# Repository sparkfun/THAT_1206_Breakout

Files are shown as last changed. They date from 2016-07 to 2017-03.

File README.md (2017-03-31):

SparkFun THAT 1206 Breakout
========================================

THAT-1206 Breakout

[*BOB-14002*](https://www.sparkfun.com/products/14002)

The SparkFun THAT 1206 InGenius Breakout Board offers an easy solution to adding a balanced audio input to your circuits. The THAT InGenius technology has been designed for high-grade analog line receiving and offers a low distortion and high common mode rejection in real-world audio applications. Each breakout board combines the THAT 1206 IC, its supporting components, and a ¼" TRS (Tip Ring Sleeve) socket. With these powers combined, you will find it very easy to use the input drivers on breadboards and in projects!

The THAT 1206 InGenius Breakout and its sibling, the THAT 1646 OutSmarts Breakout, perform mirror-image signal conversion. While the OutSmarts is an unbalanced-to-balanced output driver, this InGenius is a balanced-to-unbalanced input receiver. We have made sure to break out each pin you need to utilize the InGenius board, including the unbalanced output (OUT), the positive and negative power supply rails (V+, V-) and, of course, ground (GND). Additionally, adjacent to each leg of the socket are test points for the signal (T, R, S) and normal (TN, RN, SN) contacts.

Repository Contents
-------------------

* **/Hardware** - Eagle design files (.brd, .sch)
* **/Production** - Production panel files (.brd)

Documentation
--------------
* **[Hookup Guide](https://learn.sparkfun.com/tutorials/that-ingenuis-and-outsmarts-breakout-hookup-guide)** - Basic hookup guide for the THAT 1206 and 1646 breakouts.
* **[SparkFun Fritzing repo](https://github.com/sparkfun/Fritzing_Parts)** - Fritzing diagrams for SparkFun products.
* **[SparkFun 3D Model repo](https://github.com/sparkfun/3D_Models)** - 3D models of SparkFun products.

Product Versions
----------------
* [BOB-14002](https://www.sparkfun.com/products/14002) - THAT 1206 InGenius breakout board.
* [BOB-14003](https://www.sparkfun.com/products/14003) - The companion THAT 1646 OutSmarts breakout board.

Version History
---------------
* [V1.0 Tag](https://github.com/sparkfun/THAT_1206_Breakout/commit/8fa3e24b62fe93f8f912508c355df1751a37f655) - Files as of product launch.

License Information
-------------------

This product is _**open source**_!

Please review the LICENSE.md file for license information.

If you have any questions or concerns on licensing, please contact techsupport@sparkfun.com.

Distributed as-is; no warranty is given.

- Your friends at SparkFun.

_<COLLABORATION CREDIT>_

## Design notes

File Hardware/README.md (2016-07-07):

SparkFun <PRODUCT NAME> Design Files
=====================================

The .sch and .brd files hare are Eagle CAD schematic and PCB design files from SparkFun Electronics.
A freeware version of Eagle can be found [here](http://www.cadsoftusa.com/download-eagle/freeware/).

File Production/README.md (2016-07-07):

SparkFun <PRODUCT NAME> Production Files
=========================================

These are the production files SparkFun uses for printing PCBs.

License Information
-------------------
This product is open source! 

The hardware is released under [Creative Commons ShareAlike 4.0 International](https://creativecommons.org/licenses/by-sa/4.0/).

Please use, reuse, and modify these files as you see fit. Please maintain attribution to SparkFun Electronics and release anything derivative under the same license.

Distributed as-is; no warranty is given.

- Your friends at SparkFun.

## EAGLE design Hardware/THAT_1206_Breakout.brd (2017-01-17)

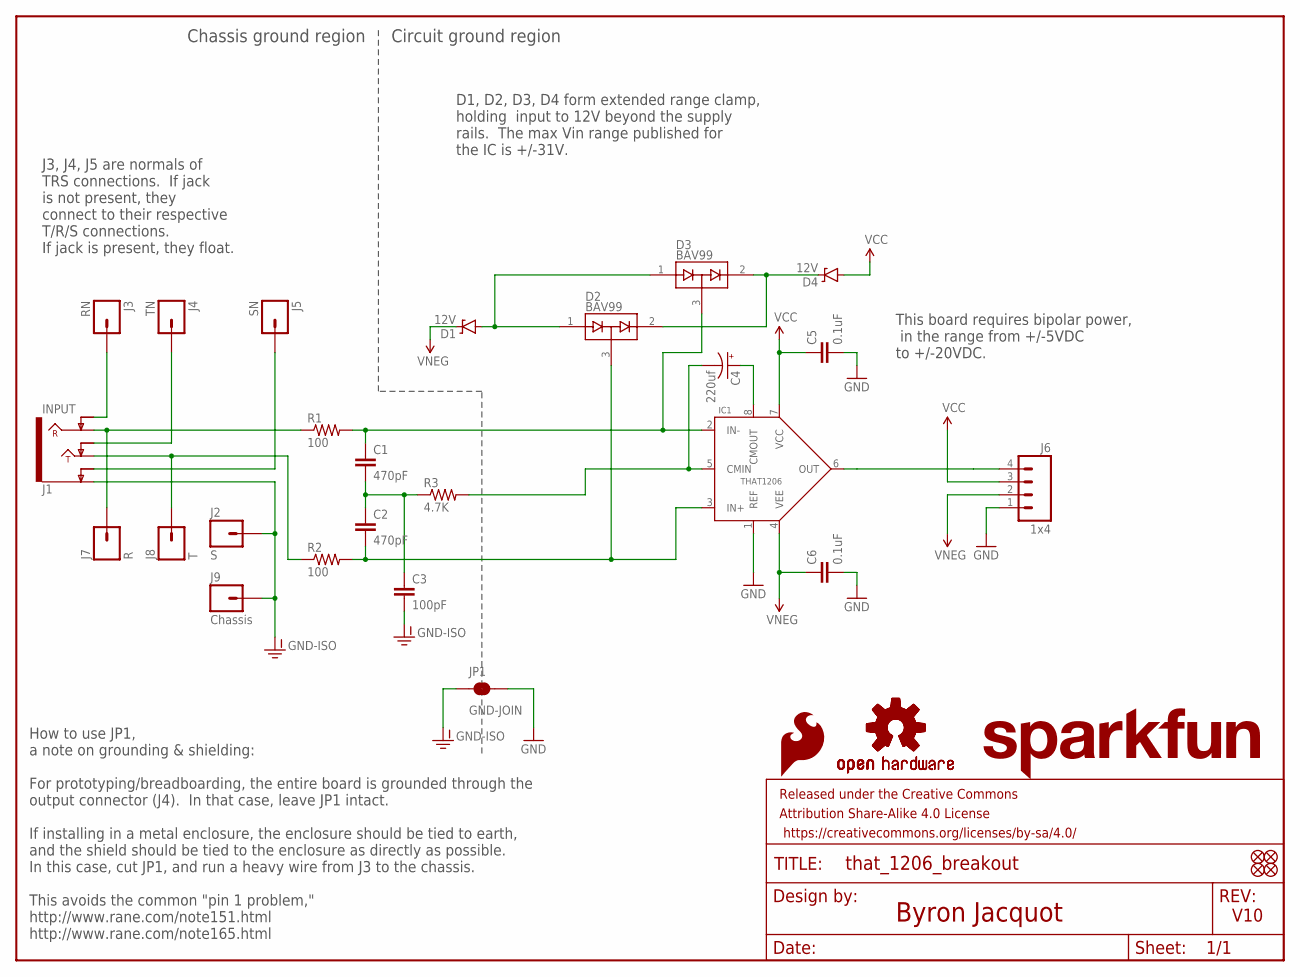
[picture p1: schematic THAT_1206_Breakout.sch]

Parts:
C1, C2: 470pF; 0603-CAP
C3: 100pF; 0603-CAP
C4: 220uf; PANASONIC_D
C5, C6: 0.1uF; 0603-CAP
D1, D4: 12V; SOD-323
D2, D3: BAV99; SOT23-3
FD1, FD2, FD3, FD4: FIDUCIALUFIDUCIAL; MICRO-FIDUCIAL
FRAME1: FRAME-LETTER; CREATIVE_COMMONS
IC1: THAT1206; SO08
J1: INPUT; AUDIO_JACK_0.25"_TRS_PTH_RA
J2: S; 1X01_NO_SILK
J3: RN; 1X01_NO_SILK
J4: TN; 1X01_NO_SILK
J5: SN; 1X01_NO_SILK
J6: 1x4; 1X04_NO_SILK_ALL_ROUND
J7: R; 1X01_NO_SILK
J8: T; 1X01_NO_SILK
J9: Chassis; 1X01_NO_SILK
JP1: GND-JOIN; PAD-JUMPER-2-NC_BY_TRACE_YES_SILK
LOGO2: SFE_LOGO_FLAME.2_INCH; SFE_LOGO_FLAME_.2
LOGO3, LOGO4: OSHW-LOGOS; OSHW-LOGO-S
LOGO5: SFE_LOGO_NAME.1_INCH; SFE_LOGO_NAME_.1
R1, R2: 100; 0603-RES
R3: 4.7K; 0603-RES

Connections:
GND: C5.2, C6.2, IC1.1 (REF), J6.1, JP1.2
GND-ISO: C3.2, J1.SLEEVE (EARTH), J2.1, J9.1, JP1.1
unnamed: J1.RING, J7.1, R1.1
unnamed: C1.1, D3.3 (COM), IC1.2 (IN-), R1.2
unnamed: J1.TIP, J8.1, R2.1
unnamed: C2.2, D2.3 (COM), IC1.3 (IN+), R2.2
unnamed: C1.2, C2.1, C3.1, R3.1
unnamed: C4.-, IC1.5 (CMIN), R3.2
unnamed: C4.+, IC1.8 (CMOUT)
unnamed: J1.SLEEVE-NORM (EARTH-NORM), J5.1
unnamed: J1.TIP-NORM, J4.1
unnamed: J1.RING-NORM, J3.1
unnamed: D1.A, D2.1 (A1), D3.1 (A1)
unnamed: D2.2 (C2), D3.2 (C2), D4.C
RCV: IC1.6 (OUT), J6.4
VCC: C5.1, D4.A, IC1.7 (VCC), J6.3
VNEG: C6.1, D1.C, IC1.4 (VEE), J6.2

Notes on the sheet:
Byron Jacquot
V10
How to use JP1, a note on grounding & shielding: For prototyping/breadboarding, the entire board is grounded through the output connector (J4). In that case, leave JP1 intact. If installing in a metal enclosure, the enclosure should be tied to earth, and the shield should be tied to the enclosure a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
This board requires bipolar power, in the range from +/-5VDC to +/-20VDC.
Chassis ground region
Circuit ground region
D1, D2, D3, D4 form extended range clamp, holding input to 12V beyond the supply rails. The max Vin range published for the IC is +/-31V.
J3, J4, J5 are normals of TRS connections. If jack is not present, they connect to their respective T/R/S connections. If jack is present, they float.

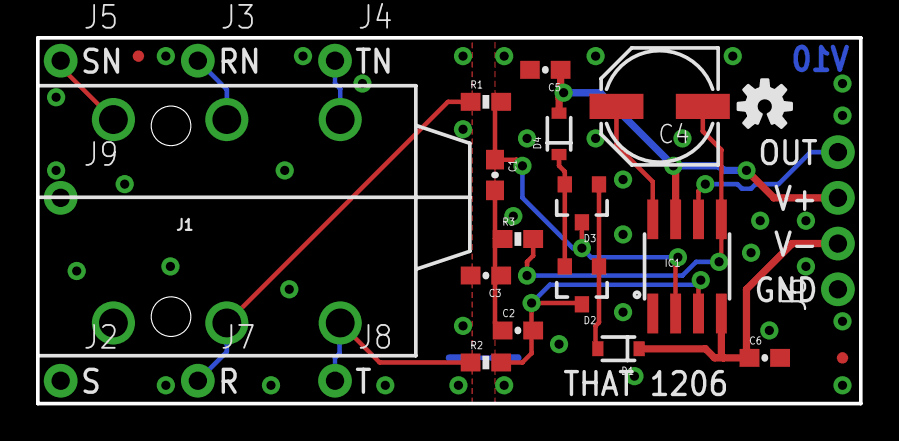
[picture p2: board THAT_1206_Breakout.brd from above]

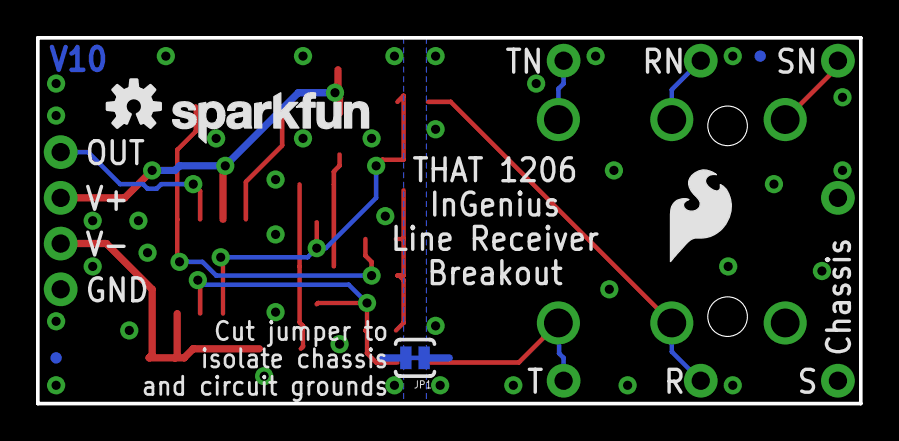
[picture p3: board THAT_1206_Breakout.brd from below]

Board: 2 copper layers, 45.7 x 20.3 mm, 33 parts (6 on the bottom side), 17 nets.

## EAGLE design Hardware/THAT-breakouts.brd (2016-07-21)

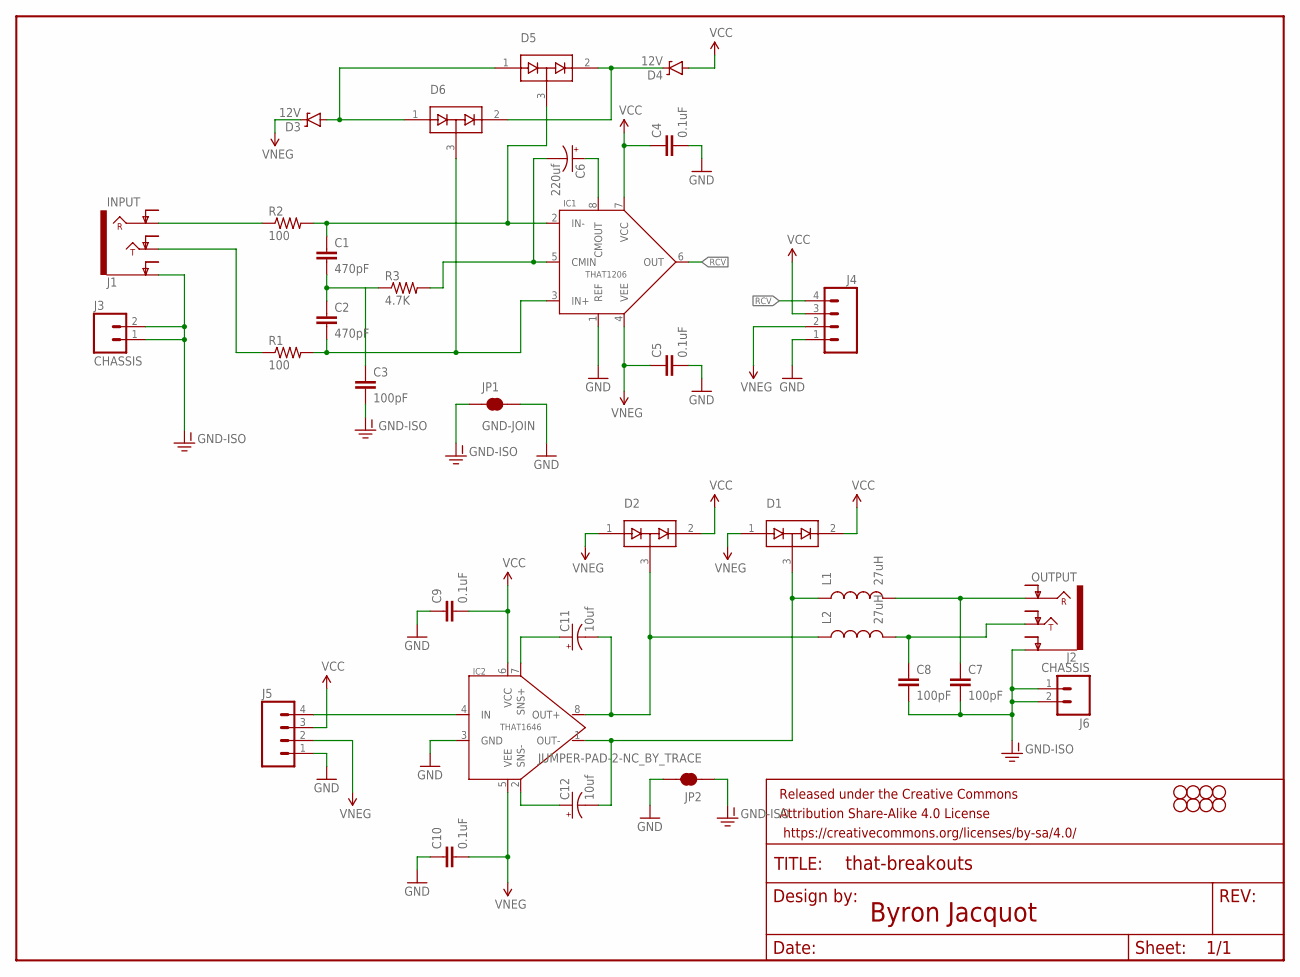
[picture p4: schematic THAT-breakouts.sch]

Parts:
C1, C2: 470pF; 0603-CAP
C3, C7, C8: 100pF; 0603-CAP
C4, C5, C9, C10: 0.1uF; 0603-CAP
C6: 220uf; PANASONIC_D
C11, C12: 10uf; PANASONIC_D
D1, D2, D5, D6: BAV99; SOT23-3
D3, D4: 12V; SOD-323
FRAME1: FRAME-LETTER; CREATIVE_COMMONS
H1, H2, H3, H4, H5, H6, H7, H8: STAND-OFF
IC1: THAT1206; SO08
IC2: THAT1646; SO08
J1: INPUT; AUDIO-JACK-.25-INCH-HORIZ-PTH
J2: OUTPUT; AUDIO-JACK-.25-INCH-HORIZ-PTH
J3, J6: CHASSIS; 1X02_NO_SILK
J4, J5: M04NO_SILK_ALL_ROUND; 1X04_NO_SILK_ALL_ROUND
JP1: GND-JOIN; PAD-JUMPER-2-NC_BY_TRACE_YES_SILK
JP2: JUMPER-PAD-2-NC_BY_TRACE; PAD-JUMPER-2-NC_BY_TRACE_YES_SILK
L1, L2: 27uH; 0603
R1, R2: 100; 0603-RES
R3: 4.7K; 0603-RES

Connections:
GND: C4.2, C5.2, C9.1, C10.1, IC1.1 (REF), IC2.3 (GND), J4.1, J5.1, JP1.2, JP2.2
GND-ISO: C3.2, C7.2, C8.2, J1.SLEEVE (EARTH), J2.SLEEVE (EARTH), J3.1, J3.2, J6.1, J6.2, JP1.1, JP2.1
unnamed: J1.RING, R2.1
unnamed: C1.1, D5.3 (COM), IC1.2 (IN-), R2.2
unnamed: J1.TIP, R1.1
unnamed: C2.2, D6.3 (COM), IC1.3 (IN+), R1.2
unnamed: C1.2, C2.1, C3.1, R3.1
unnamed: C6.-, IC1.5 (CMIN), R3.2
unnamed: C6.+, IC1.8 (CMOUT)
unnamed: C8.1, J2.TIP, L2.2
unnamed: C7.1, J2.RING, L1.2
unnamed: C11.-, D2.3 (COM), IC2.8 (OUT+), L2.1
unnamed: C12.-, D1.3 (COM), IC2.1 (OUT-), L1.1
unnamed: D3.A, D5.1 (A1), D6.1 (A1)
unnamed: C12.+, IC2.2 (SNS-)
unnamed: C11.+, IC2.7 (SNS+)
unnamed: D4.C, D5.2 (C2), D6.2 (C2)
unnamed: IC2.4 (IN), J5.4
RCV: IC1.6 (OUT), J4.4
VCC: C4.1, C9.2, D1.2 (C2), D2.2 (C2), D4.A, IC1.7 (VCC), IC2.6 (VCC), J4.3, J5.3
VNEG: C5.1, C10.2, D1.1 (A1), D2.1 (A1), D3.C, IC1.4 (VEE), IC2.5 (VEE), J4.2, J5.2

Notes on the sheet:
Byron Jacquot

Board: 2 copper layers, 42 parts (2 on the bottom side), 21 nets, no tracks yet.

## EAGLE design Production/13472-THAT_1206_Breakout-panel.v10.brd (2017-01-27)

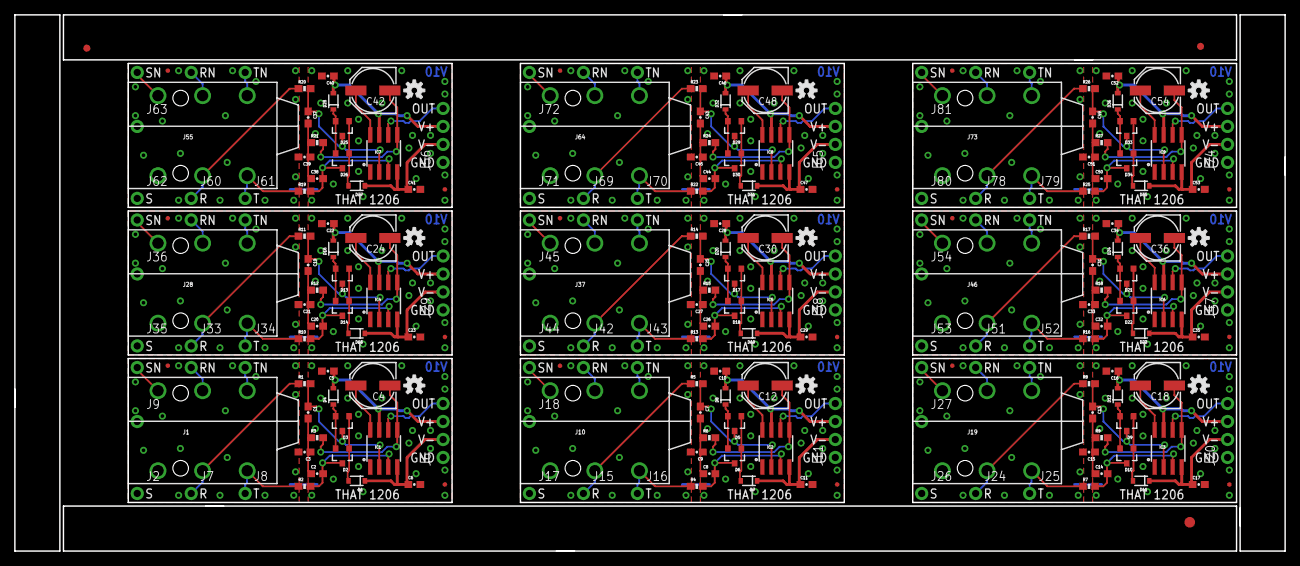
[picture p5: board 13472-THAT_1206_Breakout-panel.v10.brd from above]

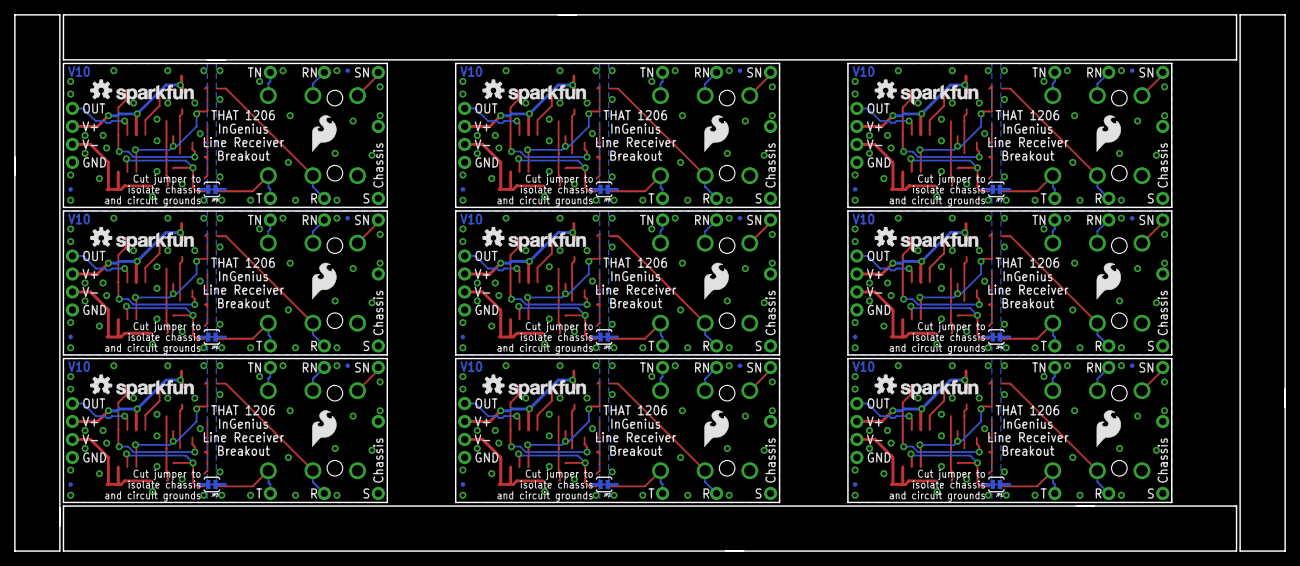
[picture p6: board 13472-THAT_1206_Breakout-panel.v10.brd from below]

Board: 2 copper layers, 179.3 x 75.7 mm, 291 parts (54 on the bottom side), 153 nets.

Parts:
C1, C2, C7, C8, C13, C14, C19, C20, C25, C26, C31, C32, C37, C38, C43, C44, C49, C50: 470pF; 0603-CAP
C3, C9, C15, C21, C27, C33, C39, C45, C51: 100pF; 0603-CAP
C4, C12, C18, C24, C30, C36, C42, C48, C54: 220uf; PANASONIC_D
C5, C6, C10, C11, C16, C17, C22, C23, C28, C29, C34, C35, C40, C41, C46, C47, C52, C53: 0.1uF; 0603-CAP
D1, D4, D7, D8, D11, D12, D15, D16, D19, D20, D23, D24, D27, D28, D31, D32, D35, D36: 12V; SOD-323
D2, D3, D5, D6, D9, D10, D13, D14, D17, D18, D21, D22, D25, D26, D29, D30, D33, D34: BAV99; SOT23-3
E$1: FIDUCIAL-1.5X3
E$7, E$8: FIDUCIAL-1X2
FD1, FD2, FD3, FD4, FD5, FD6, FD7, FD8, FD9, FD10, FD11, FD12, FD13, FD14, FD15, FD16, FD17, FD18, FD19, FD20, FD21, FD22, FD23, FD24, FD25, FD26, FD27, FD28, FD29, FD30, FD31, FD32, FD33, FD34, FD35, FD36: FIDUCIALUFIDUCIAL; MICRO-FIDUCIAL
IC1, IC2, IC3, IC4, IC5, IC6, IC7, IC8, IC9: THAT1206; SO08
J1, J10, J19, J28, J37, J46, J55, J64, J73: INPUT; AUDIO_JACK_0.25"_TRS_PTH_RA
J2, J17, J26, J35, J44, J53, J62, J71, J80: S; 1X01_NO_SILK
J3, J12, J21, J30, J39, J48, J57, J66, J75: RN; 1X01_NO_SILK
J4, J13, J22, J31, J40, J49, J58, J67, J76: TN; 1X01_NO_SILK
J5, J14, J23, J32, J41, J50, J59, J68, J77: SN; 1X01_NO_SILK
J6, J11, J20, J29, J38, J47, J56, J65, J74: 1x4; 1X04_NO_SILK_ALL_ROUND
J7, J15, J24, J33, J42, J51, J60, J69, J78: R; 1X01_NO_SILK
J8, J16, J25, J34, J43, J52, J61, J70, J79: T; 1X01_NO_SILK
J9, J18, J27, J36, J45, J54, J63, J72, J81: Chassis; 1X01_NO_SILK
JP1, JP2, JP3, JP4, JP5, JP6, JP7, JP8, JP9: GND-JOIN; PAD-JUMPER-2-NC_BY_TRACE_YES_SILK
LOGO1, LOGO3, LOGO4, LOGO6, LOGO9, LOGO10, LOGO13, LOGO14, LOGO17, LOGO18, LOGO21, LOGO22, LOGO25, LOGO26, LOGO29, LOGO30, LOGO33, LOGO34: OSHW-LOGOS; OSHW-LOGO-S
LOGO2, LOGO7, LOGO11, LOGO15, LOGO19, LOGO23, LOGO27, LOGO31, LOGO35: SFE_LOGO_FLAME.2_INCH; SFE_LOGO_FLAME_.2
LOGO5, LOGO8, LOGO12, LOGO16, LOGO20, LOGO24, LOGO28, LOGO32, LOGO36: SFE_LOGO_NAME.1_INCH; SFE_LOGO_NAME_.1
R1, R2, R4, R5, R7, R8, R10, R11, R13, R14, R16, R17, R19, R20, R22, R23, R25, R26: 100; 0603-RES
R3, R6, R9, R12, R15, R18, R21, R24, R27: 4.7K; 0603-RES

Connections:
GND: C5.2, C6.2, IC1.1, J6.1, JP1.2
GND1: C10.2, C11.2, IC2.1, J11.1, JP2.2
GND2: C16.2, C17.2, IC3.1, J20.1, JP3.2
GND3: C22.2, C23.2, IC4.1, J29.1, JP4.2
GND4: C28.2, C29.2, IC5.1, J38.1, JP5.2
GND5: C34.2, C35.2, IC6.1, J47.1, JP6.2
GND6: C40.2, C41.2, IC7.1, J56.1, JP7.2
GND7: C46.2, C47.2, IC8.1, J65.1, JP8.2
GND8: C52.2, C53.2, IC9.1, J74.1, JP9.2
GND-ISO: C3.2, J1.SLEEVE, J2.1, J9.1, JP1.1
GND-ISO1: C9.2, J10.SLEEVE, J17.1, J18.1, JP2.1
GND-ISO2: C15.2, J19.SLEEVE, J26.1, J27.1, JP3.1
GND-ISO3: C21.2, J28.SLEEVE, J35.1, J36.1, JP4.1
GND-ISO4: C27.2, J37.SLEEVE, J44.1, J45.1, JP5.1
GND-ISO5: C33.2, J46.SLEEVE, J53.1, J54.1, JP6.1
GND-ISO6: C39.2, J55.SLEEVE, J62.1, J63.1, JP7.1
GND-ISO7: C45.2, J64.SLEEVE, J71.1, J72.1, JP8.1
GND-ISO8: C51.2, J73.SLEEVE, J80.1, J81.1, JP9.1
unnamed: J1.RING, J7.1, R1.1
unnamed: C1.1, D3.3, IC1.2, R1.2
unnamed: J1.TIP, J8.1, R2.1
unnamed: C2.2, D2.3, IC1.3, R2.2
unnamed: C1.2, C2.1, C3.1, R3.1
unnamed: C4.-, IC1.5, R3.2
unnamed: C4.+, IC1.8
unnamed: J1.SLEEVE-NORM, J5.1
unnamed: J1.TIP-NORM, J4.1
unnamed: J1.RING-NORM, J3.1
unnamed: J10.RING, J15.1, R5.1
unnamed: D1.A, D2.1, D3.1
unnamed: C7.1, D5.3, IC2.2, R5.2
unnamed: J10.TIP, J16.1, R4.1
unnamed: D2.2, D3.2, D4.C
unnamed: C8.2, D6.3, IC2.3, R4.2
unnamed: C7.2, C8.1, C9.1, R6.1
unnamed: C12.-, IC2.5, R6.2
unnamed: C12.+, IC2.8
unnamed: D5.1, D6.1, D7.A
unnamed: D5.2, D6.2, D8.C
unnamed: J10.SLEEVE-NORM, J14.1
unnamed: J10.TIP-NORM, J13.1
unnamed: J10.RING-NORM, J12.1
unnamed: J19.RING, J24.1, R8.1
unnamed: C13.1, D9.3, IC3.2, R8.2
unnamed: J19.TIP, J25.1, R7.1
unnamed: C14.2, D10.3, IC3.3, R7.2
unnamed: C13.2, C14.1, C15.1, R9.1
unnamed: C18.-, IC3.5, R9.2
unnamed: C18.+, IC3.8
unnamed: D9.1, D10.1, D11.A
unnamed: D9.2, D10.2, D12.C
unnamed: J19.SLEEVE-NORM, J23.1
unnamed: J19.TIP-NORM, J22.1
unnamed: J19.RING-NORM, J21.1
unnamed: J28.RING, J33.1, R11.1
unnamed: C19.1, D13.3, IC4.2, R11.2
unnamed: J28.TIP, J34.1, R10.1
unnamed: C20.2, D14.3, IC4.3, R10.2
unnamed: C19.2, C20.1, C21.1, R12.1
unnamed: C24.-, IC4.5, R12.2
unnamed: C24.+, IC4.8
unnamed: D13.1, D14.1, D15.A
unnamed: D13.2, D14.2, D16.C
unnamed: J28.SLEEVE-NORM, J32.1
unnamed: J28.TIP-NORM, J31.1
unnamed: J28.RING-NORM, J30.1
unnamed: J37.RING, J42.1, R14.1
unnamed: C25.1, D17.3, IC5.2, R14.2
unnamed: J37.TIP, J43.1, R13.1
unnamed: C26.2, D18.3, IC5.3, R13.2
unnamed: C25.2, C26.1, C27.1, R15.1
unnamed: C30.-, IC5.5, R15.2
unnamed: C30.+, IC5.8
unnamed: D17.1, D18.1, D19.A
unnamed: D17.2, D18.2, D20.C
unnamed: J37.SLEEVE-NORM, J41.1
unnamed: J37.TIP-NORM, J40.1
unnamed: J37.RING-NORM, J39.1
unnamed: J46.RING, J51.1, R17.1
unnamed: C31.1, D21.3, IC6.2, R17.2
unnamed: J46.TIP, J52.1, R16.1
unnamed: C32.2, D22.3, IC6.3, R16.2
unnamed: C31.2, C32.1, C33.1, R18.1
unnamed: C36.-, IC6.5, R18.2
unnamed: C36.+, IC6.8
unnamed: D21.1, D22.1, D23.A
unnamed: D21.2, D22.2, D24.C
unnamed: J46.SLEEVE-NORM, J50.1
unnamed: J46.TIP-NORM, J49.1
unnamed: J46.RING-NORM, J48.1
unnamed: J55.RING, J60.1, R20.1
unnamed: C37.1, D25.3, IC7.2, R20.2
unnamed: J55.TIP, J61.1, R19.1
unnamed: C38.2, D26.3, IC7.3, R19.2
unnamed: C37.2, C38.1, C39.1, R21.1
unnamed: C42.-, IC7.5, R21.2
unnamed: C42.+, IC7.8
unnamed: D25.1, D26.1, D27.A
unnamed: D25.2, D26.2, D28.C
unnamed: J55.SLEEVE-NORM, J59.1
unnamed: J55.TIP-NORM, J58.1
unnamed: J55.RING-NORM, J57.1
unnamed: J64.RING, J69.1, R23.1
unnamed: C43.1, D29.3, IC8.2, R23.2
unnamed: J64.TIP, J70.1, R22.1
unnamed: C44.2, D30.3, IC8.3, R22.2
unnamed: C43.2, C44.1, C45.1, R24.1
unnamed: C48.-, IC8.5, R24.2
unnamed: C48.+, IC8.8
unnamed: D29.1, D30.1, D31.A
unnamed: D29.2, D30.2, D32.C
unnamed: J64.SLEEVE-NORM, J68.1
unnamed: J64.TIP-NORM, J67.1
unnamed: J64.RING-NORM, J66.1
unnamed: J73.RING, J78.1, R26.1
unnamed: C49.1, D33.3, IC9.2, R26.2
unnamed: J73.TIP, J79.1, R25.1
unnamed: C50.2, D34.3, IC9.3, R25.2
unnamed: C49.2, C50.1, C51.1, R27.1
unnamed: C54.-, IC9.5, R27.2
unnamed: C54.+, IC9.8
unnamed: D33.1, D34.1, D35.A
unnamed: D33.2, D34.2, D36.C
unnamed: J73.SLEEVE-NORM, J77.1
unnamed: J73.TIP-NORM, J76.1
unnamed: J73.RING-NORM, J75.1
RCV: IC1.6, J6.4
RCV1: IC2.6, J11.4
RCV2: IC3.6, J20.4
RCV3: IC4.6, J29.4
RCV4: IC5.6, J38.4
RCV5: IC6.6, J47.4
RCV6: IC7.6, J56.4
RCV7: IC8.6, J65.4
RCV8: IC9.6, J74.4
VCC: C5.1, D4.A, IC1.7, J6.3
VCC1: C10.1, D8.A, IC2.7, J11.3
VCC2: C16.1, D12.A, IC3.7, J20.3
VCC3: C22.1, D16.A, IC4.7, J29.3
VCC4: C28.1, D20.A, IC5.7, J38.3
VCC5: C34.1, D24.A, IC6.7, J47.3
VCC6: C40.1, D28.A, IC7.7, J56.3
VCC7: C46.1, D32.A, IC8.7, J65.3
VCC8: C52.1, D36.A, IC9.7, J74.3
VNEG: C6.1, D1.C, IC1.4, J6.2
VNEG1: C11.1, D7.C, IC2.4, J11.2
VNEG2: C17.1, D11.C, IC3.4, J20.2
VNEG3: C23.1, D15.C, IC4.4, J29.2
VNEG4: C29.1, D19.C, IC5.4, J38.2
VNEG5: C35.1, D23.C, IC6.4, J47.2
VNEG6: C41.1, D27.C, IC7.4, J56.2
VNEG7: C47.1, D31.C, IC8.4, J65.2
VNEG8: C53.1, D35.C, IC9.4, J74.2

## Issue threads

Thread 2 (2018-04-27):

Unbalanced input impedance (guitar)

Rippert, 2018-04-27:
I'm looking at adding both a balanced input and a High-Z unbalanced input to an audio board with only unbalanced, low-Z inputs. Reading through the data sheet on the THAT1206 IC, it seems to be saying that the bootstrap circuit design gives the same kind of response to unbalanced inputs as a transformer. So I'm wondering if I can use the 1206 breakout board as a reasonable compromise between having a nice quiet balanced input (which it should certainly do) and a decent, if not ideal, unbalanced, high-Z input.

So, if I just plug my 1/4 inch unbalanced TS guitar cable into the TRS jack on a 1206 breakout (I know that's the worst for unbalanced interconnect, but an electric guitar is what it is), it will short the negative signal to ground, but will it and "see" a high input impedance in the MOhm range?

I have some mixers with dual use balanced and unbalanced High-Z inputs that work by just plugging in a TS cable instead of a TRS, so I know it can be done, but I don't know if your breakout board is a similar circuit or not.

Thanks
-Ted

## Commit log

2016-07-07 Initial tinkering with the idea.
    [THAT-breakouts.brd, THAT-breakouts.sch]
2016-07-08 More WIP & conceptual work.
    [THAT-breakouts.brd, THAT-breakouts.sch]
2016-07-09 Still more WIP.
    [THAT-breakouts.brd, THAT-breakouts.sch]
2016-07-21 Found some zeners...
    [THAT-breakouts.brd, THAT-breakouts.sch]
2016-07-26 Broke into 2 separate board files.
    [THAT_1206_Breakout.brd, THAT_1206_Breakout.sch, THAT_1646_Breakout.brd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]
2016-07-27 Moved 1646 to its own repo.
    [THAT_1646_Breakout.brd, THAT_1646_Breakout.sch]
2016-07-27 Routed PCB.
    [THAT_1206_Breakout.brd, THAT_1206_Breakout.sch]
2016-07-27 Updates after routing.
    Added ground stitches & dimensions.
    [THAT_1206_Breakout.brd]
2016-08-08 After proto review.
    Many fit & finish changes.
    [THAT_1206_Breakout.brd, THAT_1206_Breakout.sch]
2016-08-08 Fixing the nonpolar caps
    To have non-polarized schem symbols, and adding PROD_IDs.
    [THAT_1206_Breakout.brd]
2016-08-09 Ran engineering checklist, a few small changes.
    [THAT_1206_Breakout.brd, THAT_1206_Breakout.sch]
2016-08-09 Fixing text in schem.
    [THAT_1206_Breakout.sch]
2016-08-09 Fixing Kade's checklist issues.
    -Un-"toed."
    -Moved chassis ground connection.
    [THAT_1206_Breakout.brd, THAT_1206_Breakout.sch]
2017-01-09 Adding testpoints on T/R/S connections.
    [THAT_1206_Breakout.brd, THAT_1206_Breakout.sch]
2017-01-09 Moving PTH holes to 0.1" grid, matching size to 1646 board.
    [THAT_1206_Breakout.brd]
2017-01-16 Updates after group review.
    -Chassis ground moved out of selective solder runout path.
    -Flame turned right side up.
    -A few via/silk overlaps fixed.
    [THAT_1206_Breakout.brd, THAT_1206_Breakout.sch]
2017-01-16 Updated after running checklist.
    Biggest change is that TRS jack was updated with new libraries.
    [THAT_1206_Breakout.brd, THAT_1206_Breakout.sch]
2017-01-17 Found under-spec silk widths on the new caps and ICs.
    [THAT_1206_Breakout.brd, THAT_1206_Breakout.sch]
2017-03-31 Fixing mistake in jumper numbering in schem info.
    J9 is the one to use for grounding!
    [THAT_1206_Breakout.sch]

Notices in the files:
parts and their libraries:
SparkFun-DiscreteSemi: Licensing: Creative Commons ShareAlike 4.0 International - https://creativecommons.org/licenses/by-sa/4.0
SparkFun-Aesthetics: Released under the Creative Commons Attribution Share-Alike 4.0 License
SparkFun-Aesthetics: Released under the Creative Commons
